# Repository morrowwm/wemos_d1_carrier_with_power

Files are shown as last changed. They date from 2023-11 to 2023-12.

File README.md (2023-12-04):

# wemos_d1_carrier_with_power
Wemos D1 Mini carrier board with power DC volt output and I2C interface

This is a simple board takes input up to ~30 VDC and powers a [Wemos D1 Mini](https://universal-solder.ca/product/wemos-d1-mini-esp8266-wifi-iot-module/).
The Wemos D1 controls a MOSFET which switches the input voltage, and has I2C broken out to a 4 pin header. 

Useful for anything which senses the environment and controls something that requires more power of voltage than the D1's ESP8266 can provide. I used it to control a dough proofing oven.

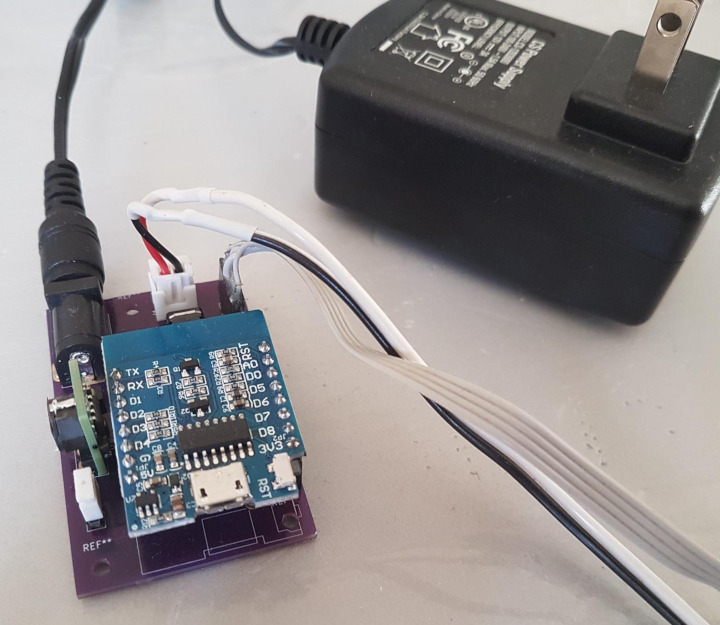
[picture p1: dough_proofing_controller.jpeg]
dough proofer


A dough proofing oven controller. Temperature and humidity sensed using an AOSONG AHT25. The MOSFET controls some silicon heating pads.

# Instructions to build
1. In both the Visual Code dough proofer include directory and the Arduino IDE heatbox source folder, there is a secrets.h file. Edit it to set WLAN_SSID1 and WLAN_PASS1 to match your wi-fi credentials. If you are using MQTT, you might want to adjust the three #defines just below to suit your setup. Also the mqtt_server variable further down.
2. What libraries you require depend on the sensors you attach.
3. On the hardware side, the 4-pin header marked J4 has D1, D2, 3V3  and GND connections, moving left to right with the edge closest to J4 facing you.

# Use
1. Before developing with the Wemos D1 connected to your computer via USB, make sure the jumper header marked J2 is __disconnected__. This will ensure you can't power the device from both the external power jack and your computer. Doing so will destroy at least the voltage regulator and possibly the Wemos D1 and your computer.
2. The code contains the ability to do OTA programming.

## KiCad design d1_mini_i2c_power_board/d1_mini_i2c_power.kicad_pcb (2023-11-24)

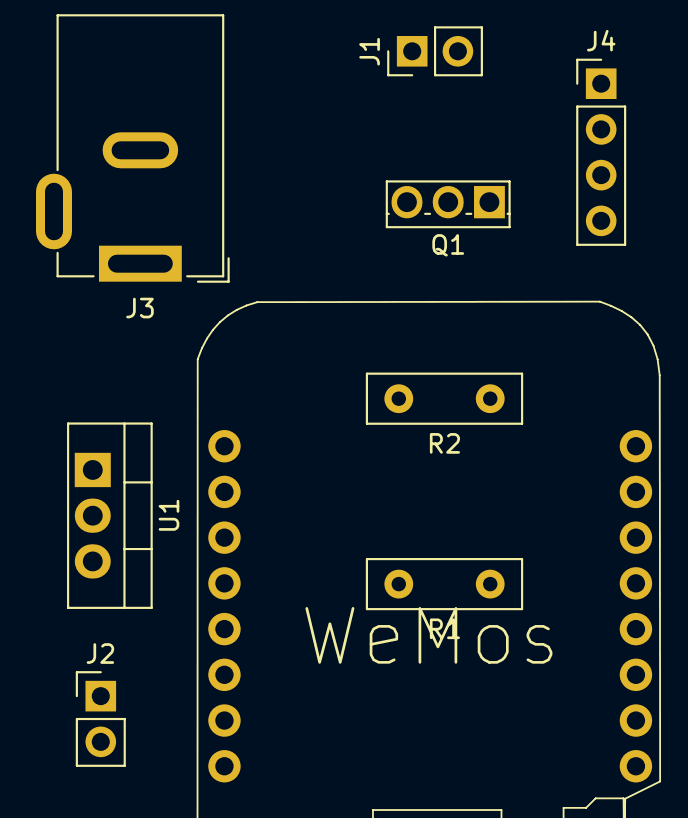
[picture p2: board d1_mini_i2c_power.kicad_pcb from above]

Board: 2 copper layers, 9 parts (0 on the bottom side), 10 nets, no tracks yet.

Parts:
J1: OUT; PinHeader_1x02_P2.54mm_Vertical
J2: Conn_01x02_Female; PinHeader_1x02_P2.54mm_Vertical
J3: Barrel_Jack; BarrelJack_GCT_DCJ200-10-A_Horizontal
J4: I2C; PinHeader_1x04_P2.54mm_Vertical
Q1: IRLU024NPBF; TO-251-3_Vertical
R1: 690; R_Box_L8.4mm_W2.5mm_P5.08mm
R2: 100K; R_Box_L8.4mm_W2.5mm_P5.08mm
U1: L7805; TO-220-3_Vertical
U2: WeMos_mini; D1_mini_board

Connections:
+3.3V: J4.2, U2.16 (3.3V)
+5V: J2.2, U2.1 (5V)
+12V: J1.1, J3.1, U1.1 (IN)
GND: J3.2, J4.1, Q1.3 (S), R2.2, U1.2 (GND), U2.2 (GND)
unnamed: J1.2, Q1.2 (D)
unnamed: J2.1, U1.3 (OUT)
unnamed: Q1.1 (G), R1.2, R2.1
unnamed: R1.1, U2.15 (D8)
unnamed: J4.3, U2.5 (D2)
unnamed: J4.4, U2.6 (D1)

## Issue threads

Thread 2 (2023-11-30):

Silk screening errors

morrowwm, 2023-11-30:
Reference error on power jumper.

I2C header should be marked D1, D2, 3.3, G

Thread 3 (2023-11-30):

Can WEMOS D1 handle USB power and external power on 5V pin simultaneously?

morrowwm, 2023-11-30:
I didn't think so, which is why there is the power jumper J2.

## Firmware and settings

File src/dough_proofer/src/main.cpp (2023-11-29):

#include <Arduino.h>
#include <Hash.h>
#include <Wire.h>
#include <ESP8266WiFi.h>
#include <PubSubClient.h>
#include <ArduinoOTA.h>
#include <NTPClient.h>
#include <AHT10.h>

#include <ESPAsyncTCP.h>
#include <ESPAsyncWebServer.h>
#include <FS.h>
#include <LittleFS.h>

#include "secrets.h"
#include "page_html.h"
const char* PARAM_SET = "target";

AHT10 aht20(AHT10_ADDRESS_0X38, AHT20_SENSOR);

WiFiClient espClient;
PubSubClient mqttClient(espClient);
WiFiUDP ntpUDP;
NTPClient timeClient(ntpUDP);

AsyncWebServer server(80);

void notFound(AsyncWebServerRequest *request) {
    request->send(404, "text/plain", "Not found");
}

time_t now;

#define HEATLAMP      D8

const unsigned long intervalNTP = 3600UL; // Update the time every hour
const unsigned long dataInterval = 2UL;   // Do a temperature measurement every N seconds

unsigned long nextReadTime = 0UL, nextPublishTime = 0UL;
int heating = 255;

float targetTemperature;
float PID_error = 0.0;
float previous_error = 0.0;
unsigned long elapsedTime, nowTime = 0, prevTime = 0;
float PID_value = 0.0;

//PID constants
float kp = 1000.0; float ki = 0.1; float kd = 100.0; 
float PID_proportional = 0; float PID_integral = 0; float PID_differential = 0;

static const char PROGMEM JSONtemplate[] = R"({"TIME":%ld,"HU":%4.2f,"TGT":%4.2f,"TE":%4.2f, "E":%f, "P":%f, "D":%f, "I":%f, "PID":%f, "HEAT":%d})";
static const char PROGMEM INFOtemplate[] = R"( Setting target temperature to: %f)";
static const char PROGMEM SYSINFOtemplate[] = R"( IP address: %s)";

char dataMessage[160];


void wifi_setup(void) {
  WiFi.mode(WIFI_STA);

  WiFi.hostname("proofer");
  WiFi.begin(WLAN_SSID1, WLAN_PASS1);
  while (WiFi.waitForConnectResult() != WL_CONNECTED) {
    Serial.println("Connection Failed! Rebooting...");
    delay(5000);
    ESP.restart();
  }

  Serial.println('\n');
  Serial.print("Connected to AP ");
  Serial.println(WiFi.SSID());              // Tell us what network we're connected to
  Serial.print("IP address:\t");
  Serial.println(WiFi.localIP());           // Send the IP address of the ESP8266 to the computer
}

void ap_setup(void) {
  WiFi.disconnect(true);
  delay(2000);
  // IPAddress local_IP(192,168,4,22);
  // IPAddress gateway(192,168,4,9);
  // IPAddress subnet(255,255,0,0);

  //Serial.print("Setting soft-AP configuration ... ");
  //Serial.println(WiFi.softAPConfig(local_IP, gateway, subnet) ? "Ready" : "Failed!");

  WiFi.mode(WIFI_AP);
    
  if(WiFi.softAP("proofer")){
    Serial.println("AP is true");
  }
  else{
    Serial.println("AP failed!");
}
  Serial.print("WAP is "); Serial.println(AP_SSID);
  Serial.println(WiFi.softAPIP());
}

void ota_setup(void){
  Serial.println("Setting up OTA...");
  ArduinoOTA.setHostname(OTAName);
  ArduinoOTA.setPassword(OTAPassword);

  ArduinoOTA.onStart([]() {
    String type;
    if (ArduinoOTA.getCommand() == U_FLASH) {
      type = "sketch";
    } else { // U_SPIFFS
      type = "filesystem";
    }

    // NOTE: if updating SPIFFS this would be the place to unmount SPIFFS using SPIFFS.end()
    Serial.println("Start updating " + type);
  });
  ArduinoOTA.onEnd([]() {
    Serial.println("\nEnd");
  });
  ArduinoOTA.onProgress([](unsigned int progress, unsigned int total) {
    Serial.printf("Progress: %u%%\r", (progress / (total / 100)));
  });
  ArduinoOTA.onError([](ota_error_t error) {
    Serial.printf("Error[%u]: ", error);
    if (error == OTA_AUTH_ERROR) Serial.println("Auth Failed");
    else if (error == OTA_BEGIN_ERROR) Serial.println("Begin Failed");
    else if (error == OTA_CONNECT_ERROR) Serial.println("Connect Failed");
    else if (error == OTA_RECEIVE_ERROR) Serial.println("Receive Failed");
    else if (error == OTA_END_ERROR) Serial.println("End Failed");
  });
  ArduinoOTA.begin();
  Serial.println("OTA ready");

  pinMode(LED_BUILTIN, OUTPUT);
  digitalWrite(LED_BUILTIN, 1);
}

void callback(char* topic, byte* payload, unsigned int length) {
  String messageTemp;

  Serial.print("Message arrived [");
  Serial.print(topic);
  Serial.print("] ");
  for (unsigned int i = 0; i < length; i++) {
    messageTemp += (char)payload[i];
  }
  Serial.println(messageTemp);
  if (String(topic) == "ha/proofer/cmd") {
    char info[64];

    if(messageTemp.substring(0,8) == "SETTEMP:"){
      targetTemperature = messageTemp.substring(8).toFloat();
      snprintf_P(info, sizeof(info), INFOtemplate, targetTemperature);
    }
    else if(messageTemp.substring(0,8) == "INFO"){
      snprintf_P(info, sizeof(info), SYSINFOtemplate, WiFi.localIP().toString().c_str());
    }
    else if(messageTemp.substring(0,5) == "CLEAR"){
      PID_proportional = 0.0; PID_integral = 0.0; PID_differential = 0.0;
      strcpy(info, "Cleared PID factors");

    }
    mqttClient.publish("ha/proofer/info", info);
  }
}

void mqtt_setup() {
  mqttClient.setServer(mqtt_server, 1883);
  mqttClient.setCallback(callback);
}

void reconnect() {
  while (!mqttClient.connected()) {
    Serial.print("Attempting MQTT connection...");
    if (mqttClient.connect(mdnsName, MQTT_USERNAME, MQTT_PASSWD)) {
      Serial.println("connected");
      // Once connected, publish an announcement...
      mqttClient.publish("env", "Connect from MOSQ_USER");
      mqttClient.subscribe("ha/proofer/cmd");
    } else {
      Serial.print("failed, rc=");
      Serial.print(mqttClient.state());
      Serial.println(" try again in 2 seconds");
      // Wait 2 seconds before retrying
      delay(2000);
    }
  }
}

void web_setup(){
    server.on("/", HTTP_GET, [](AsyncWebServerRequest *request){
        request->send(200, "text/html", INDEX_HTML);
    });

    // Send a GET request to <IP>/data
    server.on("/data", HTTP_GET, [] (AsyncWebServerRequest *request) {
        request->send(200, "text/plain", dataMessage);
    });

    server.on("/set", HTTP_POST, [](AsyncWebServerRequest *request){
      String message;
      if (request->hasParam(PARAM_SET, true)) {
          message = request->getParam(PARAM_SET, true)->value();
          targetTemperature = message.toFloat();
      } else {
          message = "No message sent";
      }
      //request->send(200, "text/html", INDEX_HTML);
    });

    server.on("/code/highcharts.js", HTTP_GET, [](AsyncWebServerRequest *request){
      Serial.println("Serving highcharts.js");
      request->send(LittleFS, "/code/highcharts.js", "text/javascript");
    });

    server.onNotFound(notFound);

    server.begin();
}

void setup() {
  Serial.begin(115200);
  delay(10);

  Serial.println(F("    wi-fi..."));
  wifi_setup();
  Serial.println(F("    OTA..."));
  ota_setup();
  Serial.println(F("    AP..."));
  //ap_setup();
  Serial.println(F("    MQTT..."));
  mqtt_setup();
  Serial.println(F("    WWW..."));
  web_setup();

  if(!LittleFS.begin()){
    Serial.println("An Error has occurred while mounting LittleFS");
    return;
  }

  // Initialize an NTPClient to get time
  timeClient.begin();

  // Set offset time in seconds to adjust for your timezone, for example:
  //timeClient.setTimeOffset(-14400);

  timeClient.update();
  unsigned long now = timeClient.getEpochTime();
  Serial.print("Time from NTP: "); Serial.println(now);

  pinMode(HEATLAMP, OUTPUT);

  if(aht20.begin() == true){
    Serial.println(F("AHT2x connected")); 
  } 
  else{
    Serial.println(F("AHT2x not connected or fail to load calibration coefficient")); 
  }
  targetTemperature = aht20.readTemperature(); 

  Serial.print("\nAll set up, initial target temperature: "); Serial.println(targetTemperature);
}

long nextMsgTime = 0;

void setup_wifi() {

  delay(10);
  // We start by connecting to a WiFi network
  Serial.println();
  Serial.print("Connecting to ");
  Serial.println(WLAN_SSID1);

  WiFi.begin(WLAN_SSID1, WLAN_PASS1);

  while (WiFi.status() != WL_CONNECTED) {
    delay(500);
    Serial.print(".");
  }
  Serial.println("");
  Serial.println("WiFi connected");
  Serial.println("IP address: ");
  Serial.println(WiFi.localIP());
}

void mqtt_loop() {
  if (!mqttClient.connected()) {
    reconnect();
    delay(2000);
  }
  mqttClient.loop();
}

void loop() {
  char topic[32];

  unsigned long now = timeClient.getEpochTime();
  nowTime = millis();

  if(now > nextReadTime){
    nextReadTime = now + dataInterval;

    float temperature = aht20.readTemperature(); //read 6-bytes via I2C, takes 80 milliseconds
    float humidity = aht20.readHumidity();

    PID_error = targetTemperature - temperature;
    PID_proportional = kp * PID_error;
    PID_integral = PID_integral + (ki * PID_error);
    PID_differential = kd * (PID_error - previous_error)/(0.001*(nowTime - prevTime)); // don't forget conversion from ms to seconds
    PID_value = PID_proportional + PID_integral + PID_differential;
    
    previous_error = PID_error;
    prevTime = nowTime;

    heating = int(PID_value);
    if(heating < 0){ heating = 0;}
    if(heating > 255){ heating = 255;}
    
    analogWrite(HEATLAMP, heating); // MOSFET fires on high level

    size_t len = snprintf(topic, sizeof(topic), MQTT_TOPIC);
    if (len >= sizeof(topic)) {
      Serial.println("\n\n*** MQTT topic truncated ***\n");
    }

    len = snprintf_P(dataMessage, sizeof(dataMessage), JSONtemplate, now, humidity, targetTemperature, temperature, PID_error,
      PID_proportional, PID_differential, PID_integral, PID_value, heating);
  
    Serial.print("Publish : "); Serial.print(topic);
    Serial.print(": "); Serial.println(dataMessage);
    if(!mqttClient.publish(topic, dataMessage)) {
      Serial.println("\n\n*** mqtt publish failed ***\n");
    }
  }

  ArduinoOTA.handle();
  mqtt_loop();
}
